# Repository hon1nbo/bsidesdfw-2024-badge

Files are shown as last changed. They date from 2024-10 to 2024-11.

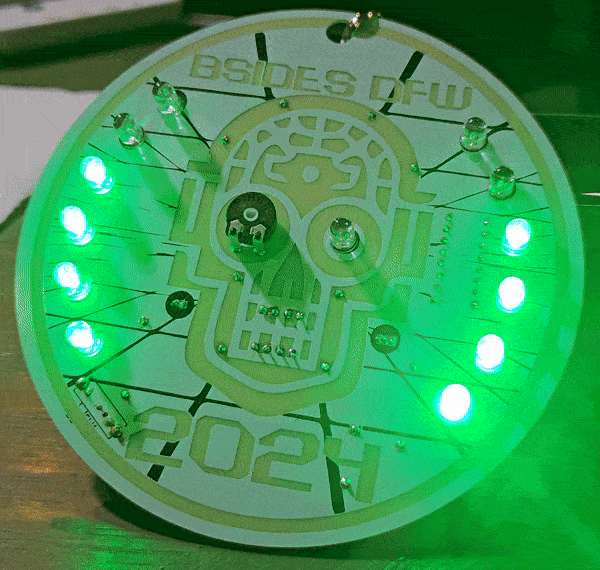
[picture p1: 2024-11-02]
images/led-chase.gif

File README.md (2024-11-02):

# bsidesdfw-2024-badge
Badge for [BSidesDFW](https://bsidesdfw.com/) and soldering kit for learners! Whilst some experienced hardware folks may think this repo is overkill for a relatively simple badge, the goal is to enable someone to do a fresh start with hardware both in assembly and simple design to try out with KiCAD. Some explanations on choices made are also included to help someone getting started understand why we did things a certain way.

## Assembly
To skip to assembly guidance, we have provided [Instructions](/INSTRUCTIONS.md).

### Badge
If you wanna see the badge in action, there's a GIF of it here (flashing lights warning): [Badge GIF](/images/led-chase.gif)

### Contributors
We're all volunteers doing this in spare time; thanks to those that helped out
- ibi5 - concept & artwork
- BearsInPorts - PCB silkscreen art
- hon1nbo - circuit design, PCB Layout

## Theory of Operation
The theory of operation for this circuit is very simple, as it's primarily intended for learning and practicing soldering. A 555 timer creates a clock signal, adjustable using a trim resistor, which feeds into the serial and clock inputs of a 74hc595 shift register. This shift register takes the serial signal and outputs a set of parallel signals to the LEDs. However, we're not really using serial data but just shifting the on/off position to the next LED in the sequence. As a note, we're using the 74xxx shift register as a Sink for the LED power so this requires a tri-state compatible variant which is available for most of the 74xxxxx series.

## EDA

### Schematic
Schematic showing a 555 clock circuit feeding a 74xxxxx series shift register into an LED matrix

### Software
[KiCAD](https://www.kicad.org/) is an open-source EDA tool for PCB and Schematic design. We highly recommend it to anyone getting started with hardware design. We used the SacSym Library Loader for parts to get usable footprints for all components. [Models](/models) are included in this repo since not every KiCAD installation uses this software default, as well as the extra silkscreen artwork located under [Art](/art). General KiCAD files are located in [KiCAD files](/KiCAD%20files), and for fabrication we have included the [Gerbers](/gerbers).

### Design Choices

#### Power
We didn't bother including any voltage regulators. Since we are using a 6v supply in the form of coin cells, and entirely through hole components, a linear regulator would be a bit inefficient and additionally the other form factors at a decent component cost would be hard for a beginner to solder. Thus to keep things simple, we stuck with using the diode's inherent voltage drop.

The LEDs used do not have a significant drop-off in lumens when chasing, and the battery life is just fine for this application based on testing with off-the-shelf 2032 batteries. 

#### Tri-State 74xxxxx logic
We went with a Tri-State 74 series shift register to simplify things. Normally, one would use the output of pins on these set to High to send out a signal. However, by using a tri-state in Sink mode (LEDs power goes to the shift register, then to ground), we were able to have a higher overall current limit across the chip. This allowed us to avoid including drive transisitors for all the LEDs and keep things simpler, and allow us to use brighter LEDs. The downside is the chip cost was ever so slightly higher than a standard 74hc595 variant.

#### Errata
AKA: Screw Ups and weird stuff

- One LED (top left front side) is out of place for the badges issued at BSides due to a shifting error from a trace re-route caused when adjusting a pad size on another component to make an unrelated tab easier to solder. The shift was not caught until after fabrication started, but it has been fixed in the KiCAD files.
- Silkscreen for LEDs is on the back. This saves the headache of multi-colour silkscreen or removing the aesthetic of the front design. We wanted to keep the dots so when unassembled it still keeps the design. The LED orientation is not affected by the silkscreen change.
- Schematic shown above still has the old +6V power taps even though the diode drops voltage. This was caught shortly before bsides; I will remove this errata line when I update that schematic after the event.

## Extra Credits
Thanks [SoberDogs](https://soberdogs.weebly.com/) for the use of the sticker art!

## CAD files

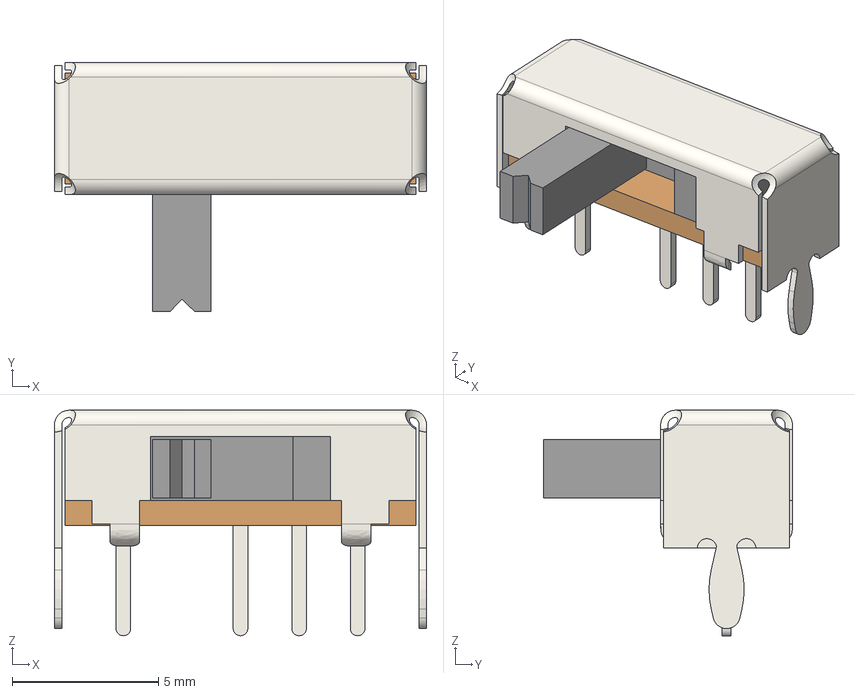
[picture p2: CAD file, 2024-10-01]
models/SLW-1274547-4A-RA-D.stp
12.7 x 8.50 x 7.70 mm

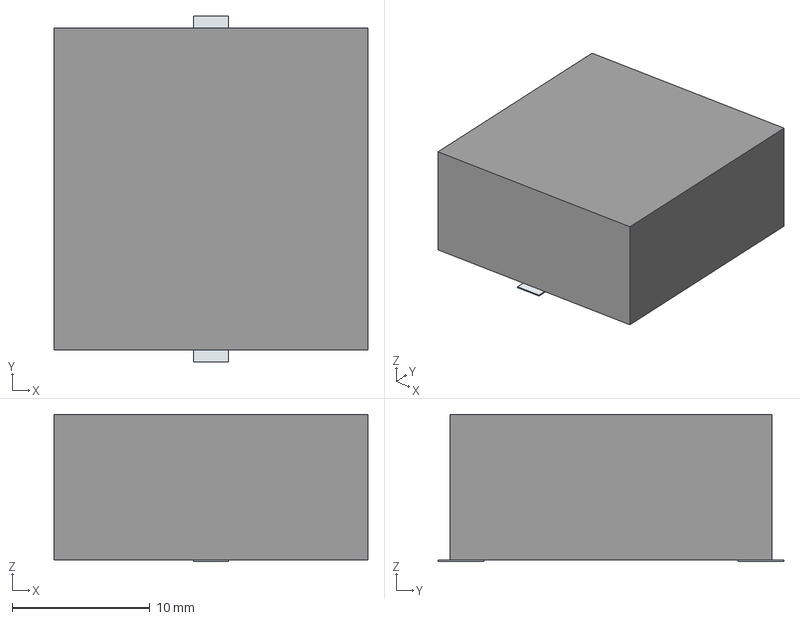
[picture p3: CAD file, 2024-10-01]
models/1062.stp
22.7 x 25.1 x 10.7 mm
Pins

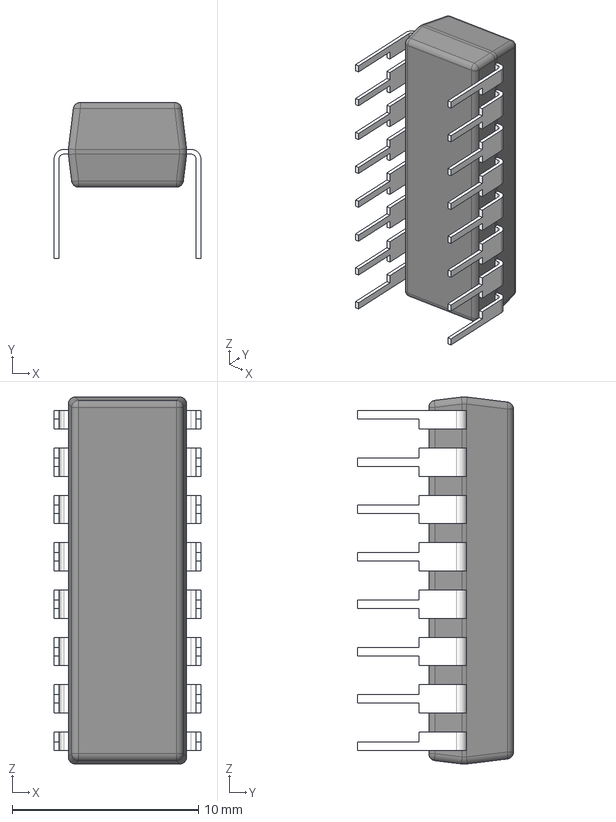
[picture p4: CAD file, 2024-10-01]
models/SN74HC595NE4.stp
7.87 x 8.37 x 19.7 mm
BODY_N0016A_AF0
LEAD_N0016A_AF1
LEAD_N0016A x 10
LEAD_N0016A_AF3
LEAD_N0016A_AF5
LEAD_N0016A_AF0
LEAD_N0016A_AF2
LEAD_N0016A_AF4

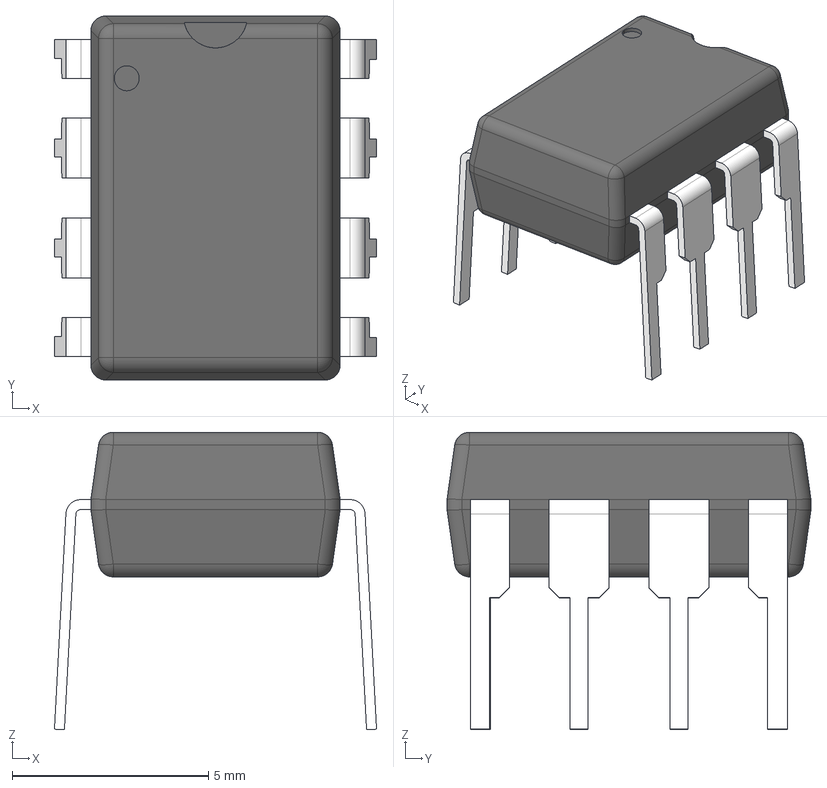
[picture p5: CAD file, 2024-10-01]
models/NE555P.stp
8.20 x 9.27 x 7.58 mm
BODY_P0008A
LEAD_P0008A x 4
LD_LHALF_P0008A x 2
LD_RHALF_P0008A x 2

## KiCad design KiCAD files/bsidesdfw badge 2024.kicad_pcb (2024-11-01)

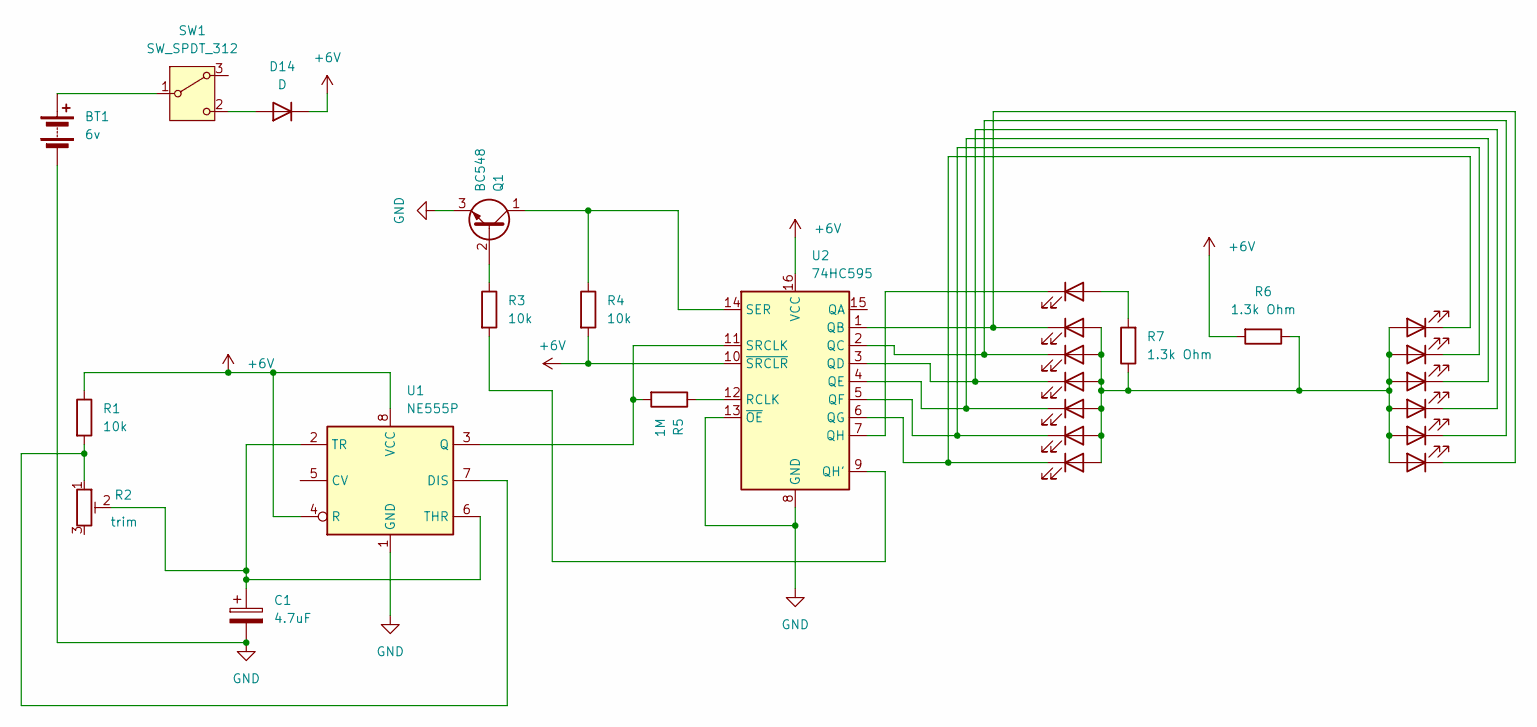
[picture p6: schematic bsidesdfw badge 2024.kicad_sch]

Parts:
BT1: 6v; 1062
C1: 4.7uF; CP_Radial_D4.0mm_P1.50mm
D1, D2, D3, D4, D5, D6, D7, D8, D9, D10, D11, D12, D13: LED_D5.0mm
D14: D; D_T-1_P10.16mm_Horizontal
Q1: BC548; TO-92_Inline
R1, R3, R4: 10k; R_Axial_DIN0309_L9.0mm_D3.2mm_P15.24mm_Horizontal
R2: trim; PT10RV10-103A0505-PM-S trim resistor
R5: 1M; R_Axial_DIN0309_L9.0mm_D3.2mm_P15.24mm_Horizontal
R6, R7: 1.3k Ohm; R_Axial_DIN0309_L9.0mm_D3.2mm_P15.24mm_Horizontal
SW1: SW_SPDT_312; SLW12745474ARAD
U1: NE555P; DIP-8_W7.62mm
U2: 74HC595; DIP794W53P254L1930H508Q16N

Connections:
+6V: D14.1 (K), R1.1, R4.2, R6.2, U1.4 (R), U1.8 (VCC), U2.10 (~SRCLR), U2.16 (VCC)
GND: BT1.2 (-), C1.2, Q1.3 (E), U1.1 (GND), U2.8 (GND), U2.13 (~OE)
unnamed: BT1.1 (+), SW1.1 (B)
unnamed: D1.2 (A), D2.2 (A), D3.2 (A), D4.2 (A), D5.2 (A), D6.2 (A), D7.2 (A), D8.2 (A), D9.2 (A), D10.2 (A), D11.2 (A), D12.2 (A), R6.1, R7.1
unnamed: D1.1 (K), D7.1 (K), U2.1 (QB)
unnamed: D2.1 (K), D8.1 (K), U2.2 (QC)
unnamed: D3.1 (K), D9.1 (K), U2.3 (QD)
unnamed: D4.1 (K), D10.1 (K), U2.4 (QE)
unnamed: D5.1 (K), D11.1 (K), U2.5 (QF)
unnamed: D6.1 (K), D12.1 (K), U2.6 (QG)
unnamed: D13.2 (A), R7.2
unnamed: D13.1 (K), U2.7 (QH)
unnamed: D14.2 (A), SW1.2 (C)
unnamed: Q1.2 (B), R3.1
unnamed: Q1.1 (C), R4.1, U2.14 (SER)
unnamed: R1.2, R2.1, U1.7 (DIS)
unnamed: R5.2, U1.3 (Q), U2.11 (SRCLK)
unnamed: C1.1, R2.2, U1.2 (TR), U1.6 (THR)
unnamed: R3.2, U2.9 (QH')
unnamed: R5.1, U2.12 (RCLK)

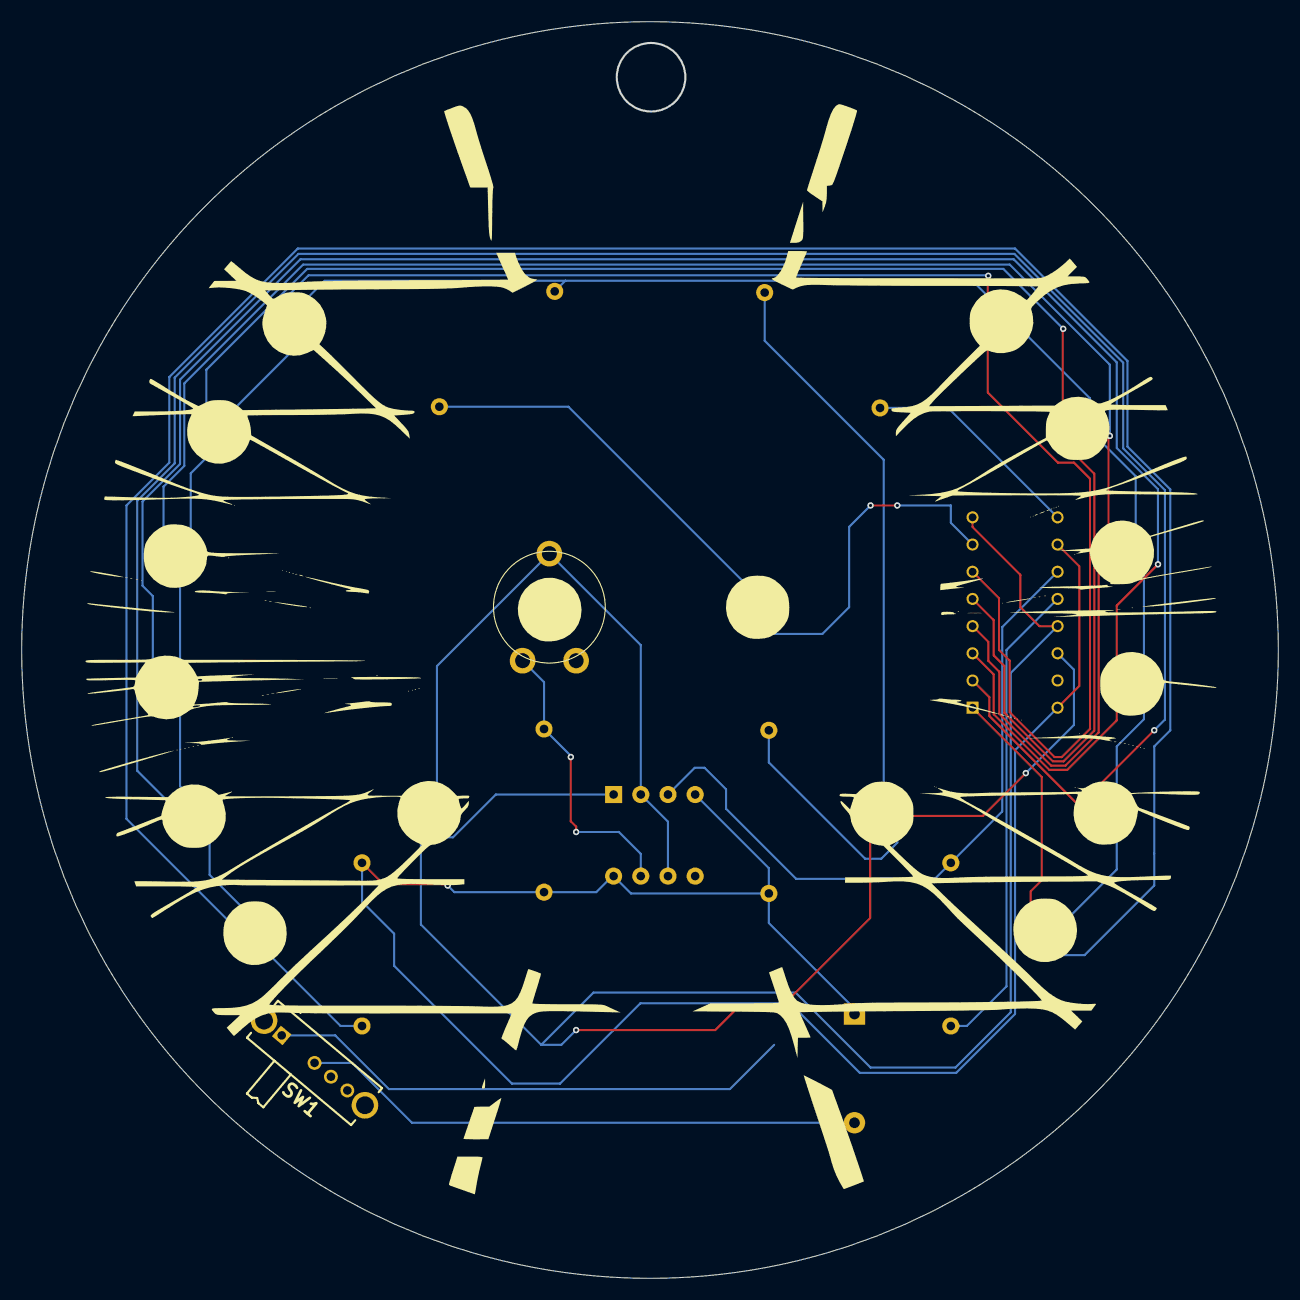
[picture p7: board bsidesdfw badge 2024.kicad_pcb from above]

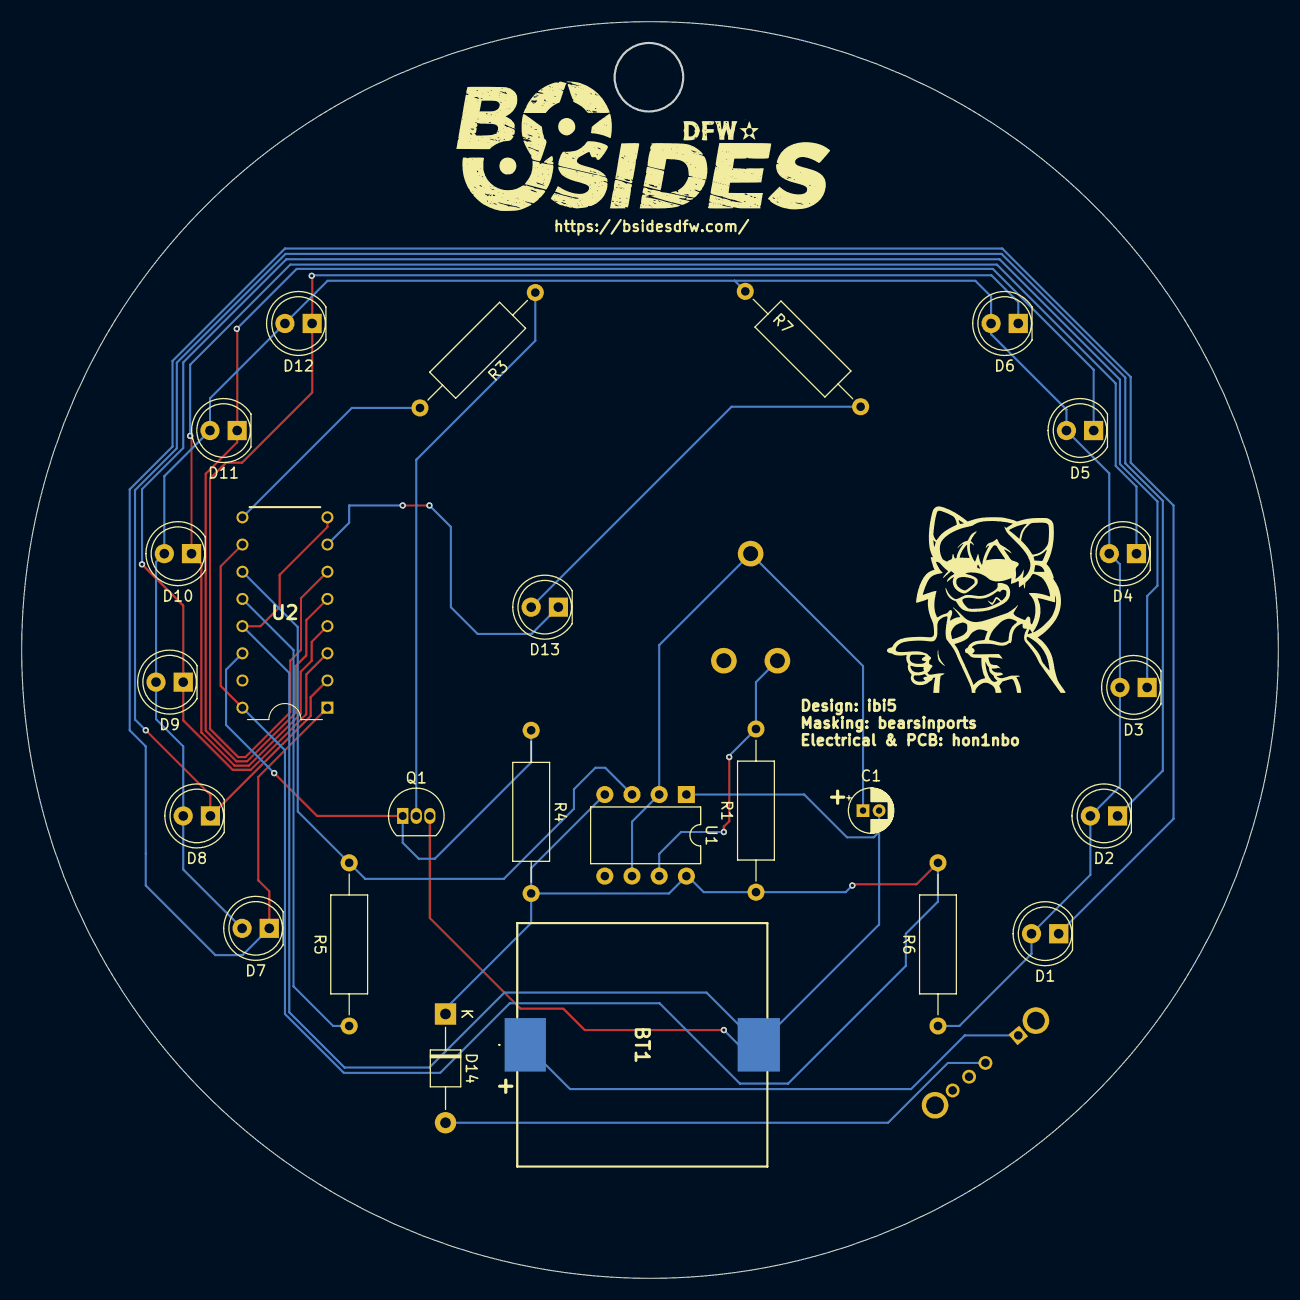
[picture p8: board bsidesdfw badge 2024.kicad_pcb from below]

Board: 2 copper layers, 117.4 x 117.4 mm, 27 parts (25 on the bottom side), 20 nets.

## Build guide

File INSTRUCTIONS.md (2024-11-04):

# BSides DFW 2024 Badge Kit Assembly Instructions

# Component List: 

* (QTY 1\) BSides DFW PCB Badge  
* (QTY 1\) 8-pin NESS59 chip (U1)   
* (QTY 3\) 10 KΩ resistors (R1, R3, R4) (Brown/Black/Orange/Gold)  
* (QTY 1\) Battery Holder (BT1)  
* (QTY 1\) Diode (D14)  
* (QTY 1\) 16-pin 74H0595 chip (U2)   
* (QTY 1\) 4.7uF capacitor (C1)  
* (QTY 1\) BC548 NPN transistor (Q1)  
* (QTY 1\) 1 MΩ resistor (R5) (Brown/Black/Green/Gold)  
* (QTY 2\) 1.3 kΩ resistors (R6, R7) (Brown/Orange/Red/Gold)   
* (QTY 1\) SPDT Switch (SW1)   
* (QTY 13\) LED diodes (D1-D13)  
* (QTY 1\) 10 kΩ Potentiometer 

# Assembly Steps: 

**WARNING:**   
**Take care to follow orientation instructions or components may be damaged\!\!\!**  
**Do not insert the batteries until you are absolutely sure the badge is assembled correctly\!\!\!**

Assemble the badge in the following order. This order ensures that you will have plenty of room to solder the component and that other components won’t get in the way. 

## BACK \- Parts should be inserted on the back side and soldered on the front side of the PCB.

1. U1 (NESS59)  \- This is the 8 pin chip.   
   1. ORIENTATION: The ***dot*** on the chip should be on the side closest to the U1 marking and the notch in the footprint. Note the Dot orientation is not the same as U2. 
        
2. R1, R3, & R4 (Brown/Black/Orange/Gold) \- No Orientation  
3. BT1 (Battery Holder)  
   1. ORIENTATION: The \+ on the component should be on the same side as the \+ on the PCB footprint (the \+ **tab** itself)
4. D14 (Diode)  
   1. ORIENTATION: The band on the component should be on the same side as the band on the PCB footprint  
5. U2 (74H0595) \- This is the 16 pin chip.  
   1. ORIENTATION: The ***notch*** on the chip should be on the side closest to the notch in the footprint. Note the Dot orientation is not the same as U1.
6. C1 (capacitor)  
   1. ORIENTATION: The longer pin on the component should be on the side with the \+ on the PCB footprint.  
   2. NOTE: INCORRECT ORIENTATION WILL RESULT IN DAMAGED COMPONENTS  
7. Q1 (transistor)  
   1. NOTE: The pins may need to be straightened to fit snugly on the PCB.  
   2. ORIENTATION: Match the flat side of the component shape with the flat side on the PCB footprint.  
8. R5 (Brown/Black/Green/Gold) \- No Orientation  
9. R6,R7 (Brown/Orange/Red/Gold) \- No Orientation  
10. SW1 (Switch) \- No Orientation
    1. This may optionally be mounted on the front of the board if desired

## FRONT \- Parts should be inserted on the front side and soldered on the back side of the PCB.

11. D1-D13 (diodes)  
    1. ORIENTATION \- Make sure the flat side of the LED matches the same direction as the flat side on the footprint on the back of the PCB. Insert LEDs on the front and solder on the back.   
    2. **NOTE: INCORRECT ORIENTATION MAY RESULT IN DAMAGED COMPONENTS**. Technically, an LED should act as a diode and prevent reverse polarity. However, the reverse voltage protection rating was not checked for this purpose so use caution.
12. Potentiometer (marking missing on the PCB, located next to D13 over an "eye")  
    1. ORIENTATION \- Only fits one way
    2. May be mounted on the back of the board if preferred; this will not affect operation
    3. When testing, Chase speed may be adjusted by turning the small notch inside the potentiometer

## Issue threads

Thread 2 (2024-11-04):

Quality of Life Improvements for future badges

hon1nbo, 2024-11-04:
More of a Lessons Learned really, as BSides has already transpired for this badge.

- Whilst the transistor being flush mounted was a better aesthetic as well as a little sturdier, the pitch of the pins was too close for many of the beginners. They all got it eventually, but it was definitely something that a lot of re-dos were needed for.
- The Capacitor wasn't quite as bad, but notable. Maybe for a part such as this we could loop at lopsiding the pad outwards so the solder can wick from a slightly further starting point to get people used to it without having to find oddly spaced components
- the vias for the ICs could be slightly larger in diameter, with an ever so slightly larger pad size (but due to density can't get too big as beginners tend to bridge)
- We had a missing silkscreen identifier for the Trim resistor. It was the only part that could fit in those holes, but it may not have been obvious to a few people.
- Evaluate 3d printing some knobs for trim resistors to include in the kits; the plastic was prone to marring with small screwdrivers. Ideally we'd have used a trim pot with an actual screwdriver head, but parts available for this purpose and specifications were not as cheap as we were trying to make this badge.
- Definitely get more solder stations and volunteers for next year; it exceeded prior year's interest significantly!

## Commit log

2024-09-29 updated number of LEDs
    [bsidesdfw badge 2024.kicad_sch]
2024-10-01 added initial PCB layout
    [bsidesdfw badge 2024.kicad_pcb]
2024-10-01 LEDs picked, resistor values updated
    [bsidesdfw badge 2024.kicad_sch]
2024-10-01 part models. trim pot needs model created
    [1062.stp, NE555P.stp, SN74HC595NE4.stp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]
2024-10-01 footprint for trim resistor
2024-10-01 add model for edge power switch
    [SLW-1274547-4A-RA-D.stp]
2024-10-01 add some various board footprints to PCB for initial layouts
    [bsidesdfw badge 2024.kicad_pcb]
2024-10-01 corrected the pin numbering for the trim resistor footprint; updated schematic to reflect trim properly
    [bsidesdfw badge 2024.kicad_pcb, bsidesdfw badge 2024.kicad_sch]
2024-10-01 adjust the 555 drive
    [bsidesdfw badge 2024.kicad_sch]
2024-10-01 unsure if last changes saved, sending away
    [bsidesdfw badge 2024.kicad_sch]
2024-10-02 fixed broken footprint assignments; laid out components. Added a diode for reverse polarity protection.
    [bsidesdfw badge 2024.kicad_pcb, bsidesdfw badge 2024.kicad_sch]
2024-10-02 placement finalized; tentative lanyard hole
    [bsidesdfw badge 2024.kicad_pcb, bsidesdfw badge 2024.kicad_sch]
2024-10-02 trace rerouting; some silkscreen cleanup. Need to remake the aesthetic mask to fix the dots overlapping the LEDs
    [bsidesdfw badge 2024.kicad_pcb, bsidesdfw badge 2024.kicad_sch]
2024-10-02 removed dimension that was weirdly in cut layer
    [bsidesdfw badge 2024.kicad_pcb]
2024-10-02 as first test boards were ordered from OSH
2024-10-03 gerbers for PCBWay; Added BSides Logo and website; added silkscreen credits for badge contributors. Moved LED footprints to back of board to address silkscreen conflicts, details are in the README.md
    [bsidesdfw badge 2024-B_Cu.gbr, bsidesdfw badge 2024-B_Mask.gbr, bsidesdfw badge 2024-B_Paste.gbr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]
2024-10-08 prototype badge tested after delivery; to make assembly easier for first timers increasing pad size for battery clip. Adding larger + indicators for some components. Generated new Gerbers
    [bsidesdfw badge 2024-B_Cu.gbr, bsidesdfw badge 2024-B_Mask.gbr, bsidesdfw badge 2024-B_Paste.gbr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]
2024-10-08 syncing some saving changes post-plotting; no material changes
2024-10-11 fixed a trace exposure from resizing battery pads; cleaned up and exported schematic to SVG for documentation.
    [bsidesdfw badge 2024-B_Cu.gbr, bsidesdfw badge 2024-B_Mask.gbr, bsidesdfw badge 2024-B_Paste.gbr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]
2024-11-01 Errata; cleaned up explanations and some other readme stuff
    [bsidesdfw badge 2024.kicad_pcb]
2024-11-02 case sensitivity typo in models link
2024-11-02 GIF of LEDs chasing on the badge
2024-11-02 Update README.md to include Schematic and link to GIF of badge in operation
2024-11-02 Correct battery holder orientation instructions
